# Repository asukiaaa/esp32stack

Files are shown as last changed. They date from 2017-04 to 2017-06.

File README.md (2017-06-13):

# ESP32Stack
A kicad project of stacking board with using ESP-WROOM-32.

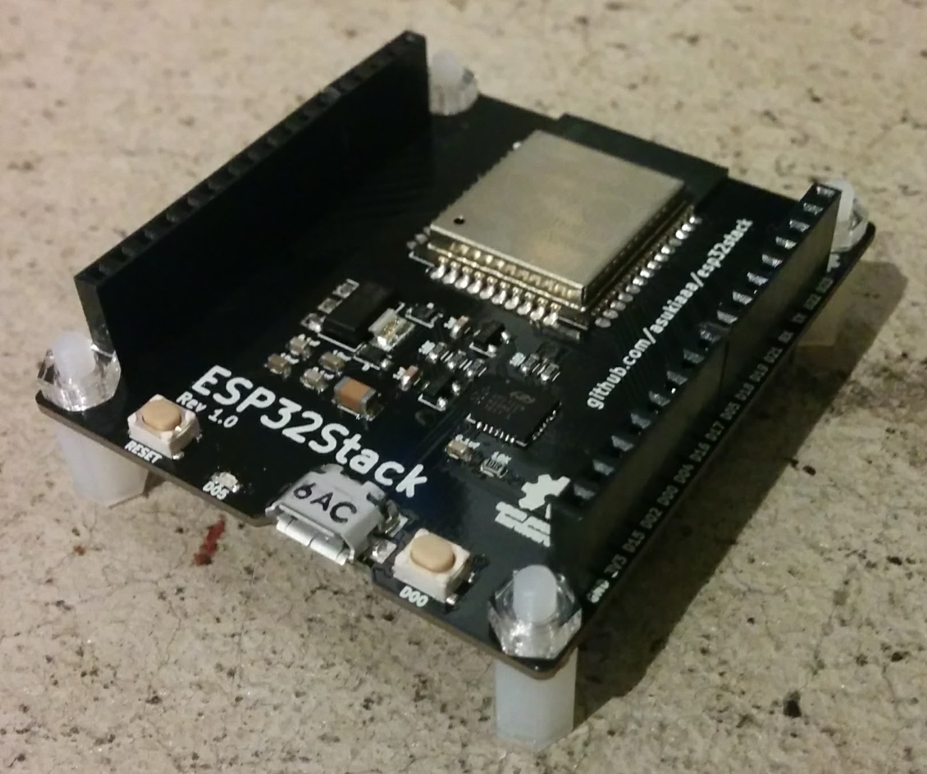
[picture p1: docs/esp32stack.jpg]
ESP32Stack

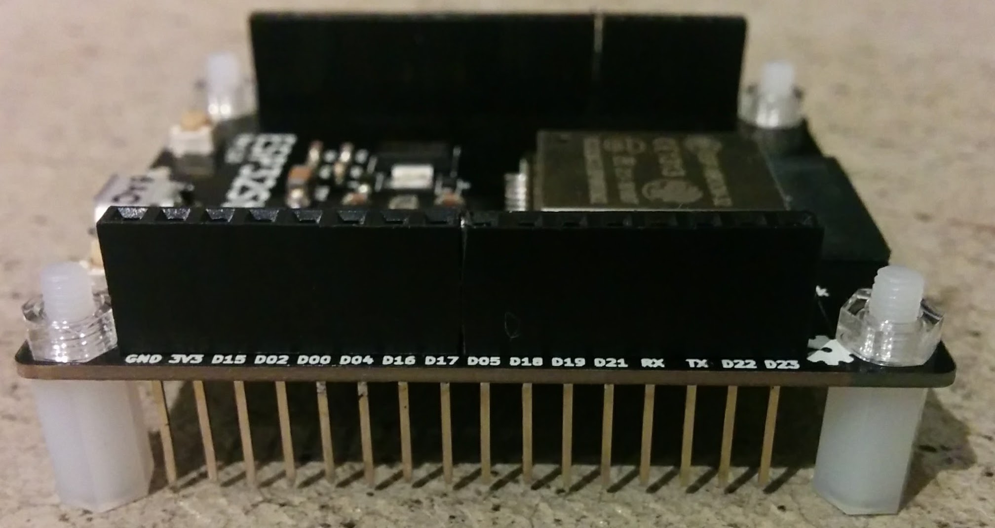
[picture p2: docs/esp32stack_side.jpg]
ESP32Stack side

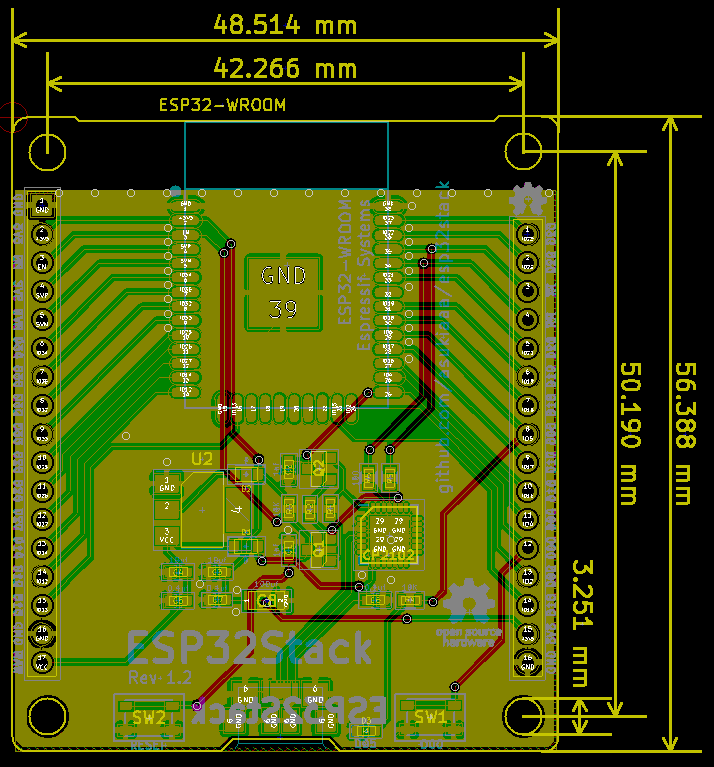
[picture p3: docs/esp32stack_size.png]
ESP32Stack size


In combination with [EmptyStack](https://github.com/asukiaaa/emptystack).
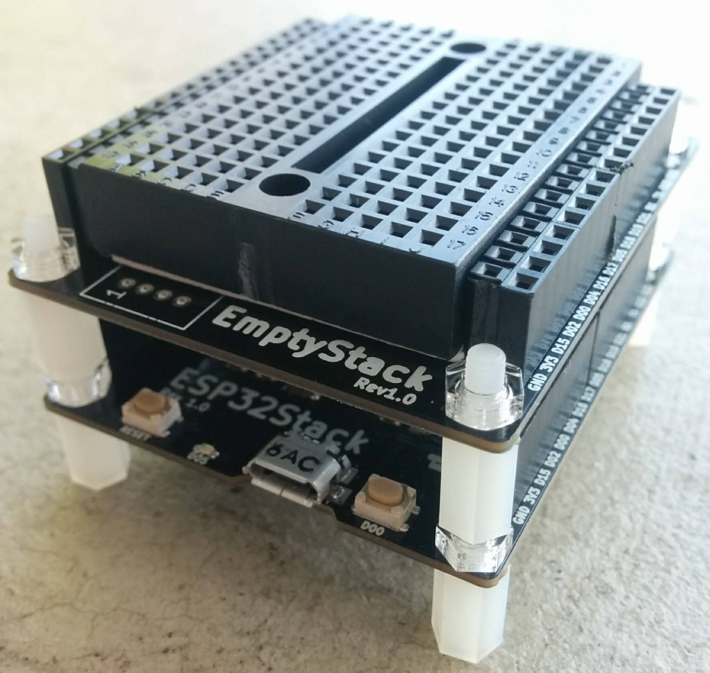
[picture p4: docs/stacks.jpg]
Stacks


[schema](docs/esp32stack.pdf)

# Driver
This board uses CP2102 for serial communication.
For mac and windiws user, please install the following driver.
Linux supports cp2102 defaul, so linux user does not need any driver.

[CP210x USB to UART Bridge VCP Drivers](http://www.silabs.com/products/development-tools/software/usb-to-uart-bridge-vcp-drivers)

# Shop
[trial stacks](https://trialstacks.base.ec/items/6243777)

# Components
- [esp-wroop-32](http://akizukidenshi.com/catalog/g/gM-11647/)
- [Hirose-microB-USB](http://akizukidenshi.com/catalog/g/gC-05254/)
- [Diode](http://akizukidenshi.com/catalog/g/gI-05951/)
- [transistor MMBT3904](http://akizukidenshi.com/catalog/g/gI-05969/)
- [switch SKRPACE010](http://akizukidenshi.com/catalog/g/gP-06185/)
- [100uf 1206 condensor](http://akizukidenshi.com/catalog/g/gP-08260/)
- [10uf 0603 condensor](http://akizukidenshi.com/catalog/g/gP-07768/)
- [0.1uf 0603 condensor](http://akizukidenshi.com/catalog/g/gP-04940/)
- [1nf (1000pf) 0603 condensor](http://akizukidenshi.com/catalog/g/gP-09285/)
- [10k 0603 registor](http://akizukidenshi.com/catalog/g/gR-06103/)
- [led](http://akizukidenshi.com/catalog/g/gI-06417/)
- [CP2102](https://www.aliexpress.com/item/5pcs-Free-shipping-SILABS-CP2102-GMR-CP2102-QFN-28-offen-use-laptop-chip-100-new-original/32503317767.html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)
- [NCP1117ST33T3G](https://www.aliexpress.com/item/Free-Shipping-NCP1117ST33T3G-NCP1117-3-3V-linear-regulator-SOT-223-package/32244660148.html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)

# Footprints
- [ESP32-kiCAD-Footprints](https://github.com/adamjvr/ESP32-kiCAD-Footprints)
- [switch: SKRPACE010.kicad_mod](https://github.com/nosuz/kicad-lib/blob/master/module.pretty/SKRPACE010.kicad_mod)

# Programing software tools
ESP32Stack is a ESP-WROOM-32 breakout board so you can write your own program by usinig the following tools.

- [espressif/esp-idf](https://github.com/espressif/esp-idf)
- [espressif/arduino-esp32](https://github.com/espressif/arduino-esp32)
- [Mongoose OS](https://mongoose-os.com/)
- etc

# License
MIT

# References
- [ESP32-Core-Board-V2_sch.pdf](http://akizukidenshi.com/download/ds/espressifsystems/ESP32-Core-Board-V2_sch.pdf)
- [esp_wroom_32_datasheet_en.pdf](https://espressif.com/sites/default/files/documentation/esp_wroom_32_datasheet_en.pdf)
- [Enginursday: First Impressions of the ESP32](https://www.sparkfun.com/news/2017)
- [ESP32 Development Board with TELEC Memorial photograph](https://macsbug.wordpress.com/2016/12/12/esp32-development-board-with-telec-memorial-photograph/)
- [DS_FT232R](http://www.ftdichip.com/Support/Documents/DataSheets/ICs/DS_FT232R.pdf)
- [SparkFun FTDI Basic Breakout - 3.3V](https://www.sparkfun.com/products/9873)
- [Sehematic of SparkFun FTDI Basic Breakout - 3.3V](http://cdn.sparkfun.com/datasheets/BreakoutBoards/FTDI%20Basic-v22-3.3V.pdf)
- [esp32-thing.sch](https://cdn.sparkfun.com/assets/learn_tutorials/5/0/7/esp32-thing-schematic.pdf)
- [The Internet of Things with ESP32](http://esp32.net/)
- [ESP-WROVER-KIT_SCH-2.pdf](https://dl.espressif.com/dl/schematics/ESP-WROVER-KIT_SCH-2.pdf)
- [ESP32-EVB_Rev_A.pdf](https://github.com/OLIMEX/ESP32-EVB/blob/master/HARDWARE/REV-A/ESP32-EVB_Rev_A.pdf)

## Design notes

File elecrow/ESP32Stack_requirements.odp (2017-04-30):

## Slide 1

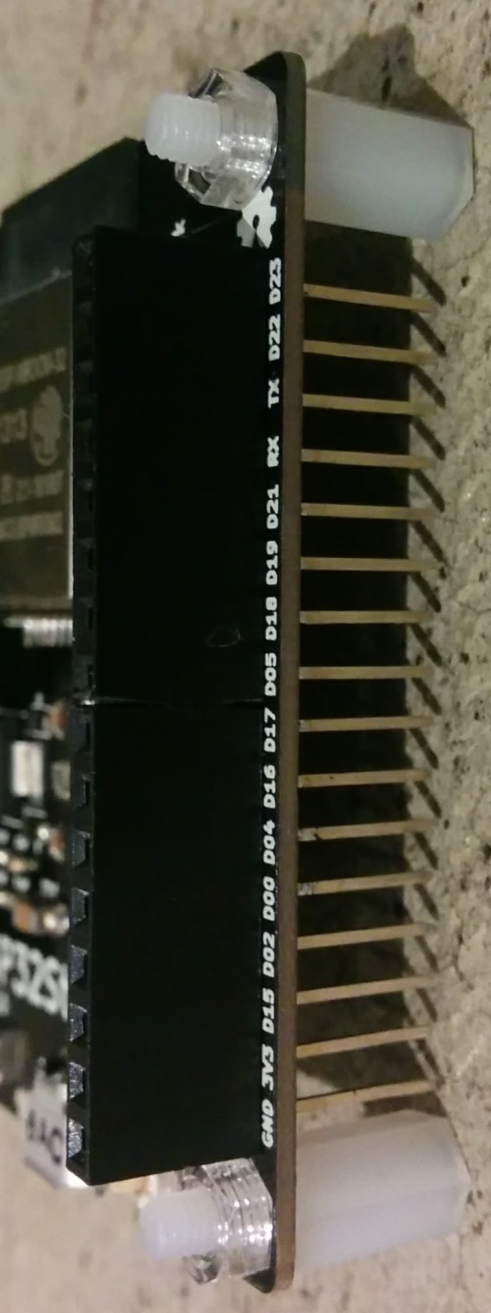
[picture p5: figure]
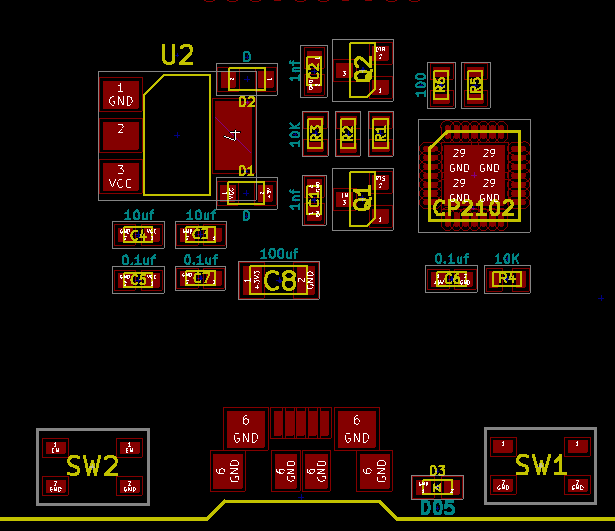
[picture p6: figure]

Component labels

Front

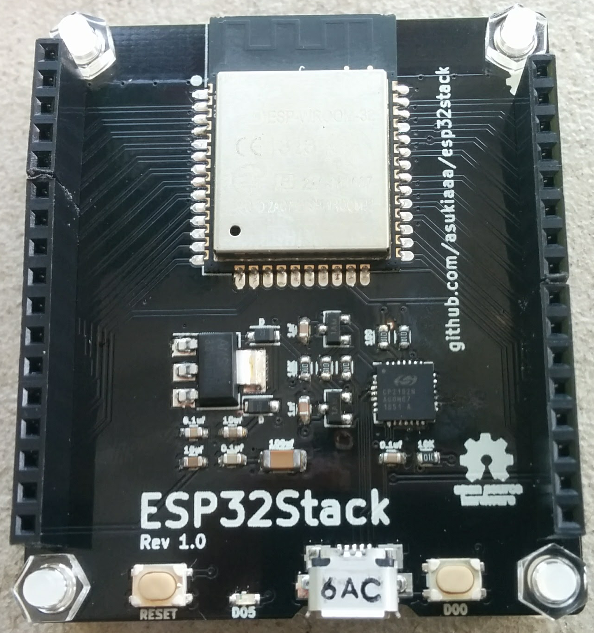
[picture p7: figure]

ESP32 module that has

TELEC mark

Side

Long leg

pin socket

(female)

Diode

→

←

Diode

Diode

←

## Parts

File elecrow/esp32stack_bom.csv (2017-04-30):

Elecrow pn | Reference | Value | Footprint | url | memo
 | P1 | USB_OTG | usb_micro_b:USB_MICRO_B-HIROSE-ZX62R-B-5P | http://www.mouser.jp/ProductDetail/Hirose-Connector/ZX62R-B-5P/?qs=XQjbzJWzFPUqfCc9Mb2Taw==
1023510A(10K) | R1,R2,R3,R4 | 10K | Resistors_SMD:R_0603
10240102A(100) | R5,R6 | 100 | Resistors_SMD:R_0603
2011501A(1nf) | C1,C2 | 1nf | Capacitors_SMD:C_0603
2015010A(10uf) | C3,C4 | 10uf | Capacitors_SMD:C_0603
 | C5,C6,C7 | 0.1uf | Capacitors_SMD:C_0603 | http://www.mouser.jp/ProductDetail/Yageo/CC0603JRNPO9BN101/?qs=AgBp2OyFlx%252bc5vUOLFsmXA== | There is no 0.1uf capacitor on list of Elecrow Parts Library. If you have any stock of 0603 size 0.1nf capacitor, please use that.
 | C8 | 100uf | Capacitors_SMD:C_1206 | http://www.mouser.jp/ProductDetail/Taiyo-Yuden/JMK316ABJ107ML-T/?qs=CNQs48zzdnrnxCTArzOO1A==
 | D1,D2 | D | common:D_0805 | http://www.mouser.jp/ProductDetail/ROHM-Semiconductor/RSX101VA-30TR/?qs=4kLU8WoGk0tB41wg4aRbGQ==
4040706A(green) | D3 | D05 | LEDs:LED_0603
 | J1 | CONN_01X17 | common:Pin_Header_Straight_1x17_Pitch2.54mm | https://www.aliexpress.com/item/8-5-0-0-10-5mm-0-1-pitch-0-4U-gold-plated-1x20-Stacking-Header/32676523255.html | Footprint is pinheader(male) but expected component is pinsocket(female) Cut the component to 17 pins or use similar one it has around 10mm length pin.
 | J2 | CONN_01X16 | common:Pin_Header_Straight_1x16_Pitch2.54mm | https://www.aliexpress.com/item/8-5-0-0-10-5mm-0-1-pitch-0-4U-gold-plated-1x20-Stacking-Header/32676523255.html | Footprint is pinheader(male) but expected component is pinsocket(female) Cut the component to 16 pins or use similar one it has around 10mm length pin.
4020290A | Q1,Q2 | MMBT3904 | TO_SOT_Packages_SMD:SOT-23
 | SW1,SW2 | SWITCH_SPST | switch:SKRPACE010 | http://www.mouser.jp/ProductDetail/ALPS/SKRPACE010/?qs=m0BA540hBPehI%2flbUxNGuw==
 | U1 | ESP32-WROOM | ESP32-footprints-Lib:ESP32-WROOM | http://akizukidenshi.com/catalog/g/gM-11850/ | Please use modules that have telec mark.
 | U2 | NCP1117ST33T3G | TO_SOT_Packages_SMD:SOT-223 | http://www.mouser.jp/ProductDetail/ON-Semiconductor/NCP1117ST33T3G/
 | U3 | CP2102 | Housings_DFN_QFN:QFN-28-1EP_5x5mm_Pitch0.5mm | http://www.mouser.jp/ProductDetail/Silicon-Labs/CP2102N-A01-GQFN28/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

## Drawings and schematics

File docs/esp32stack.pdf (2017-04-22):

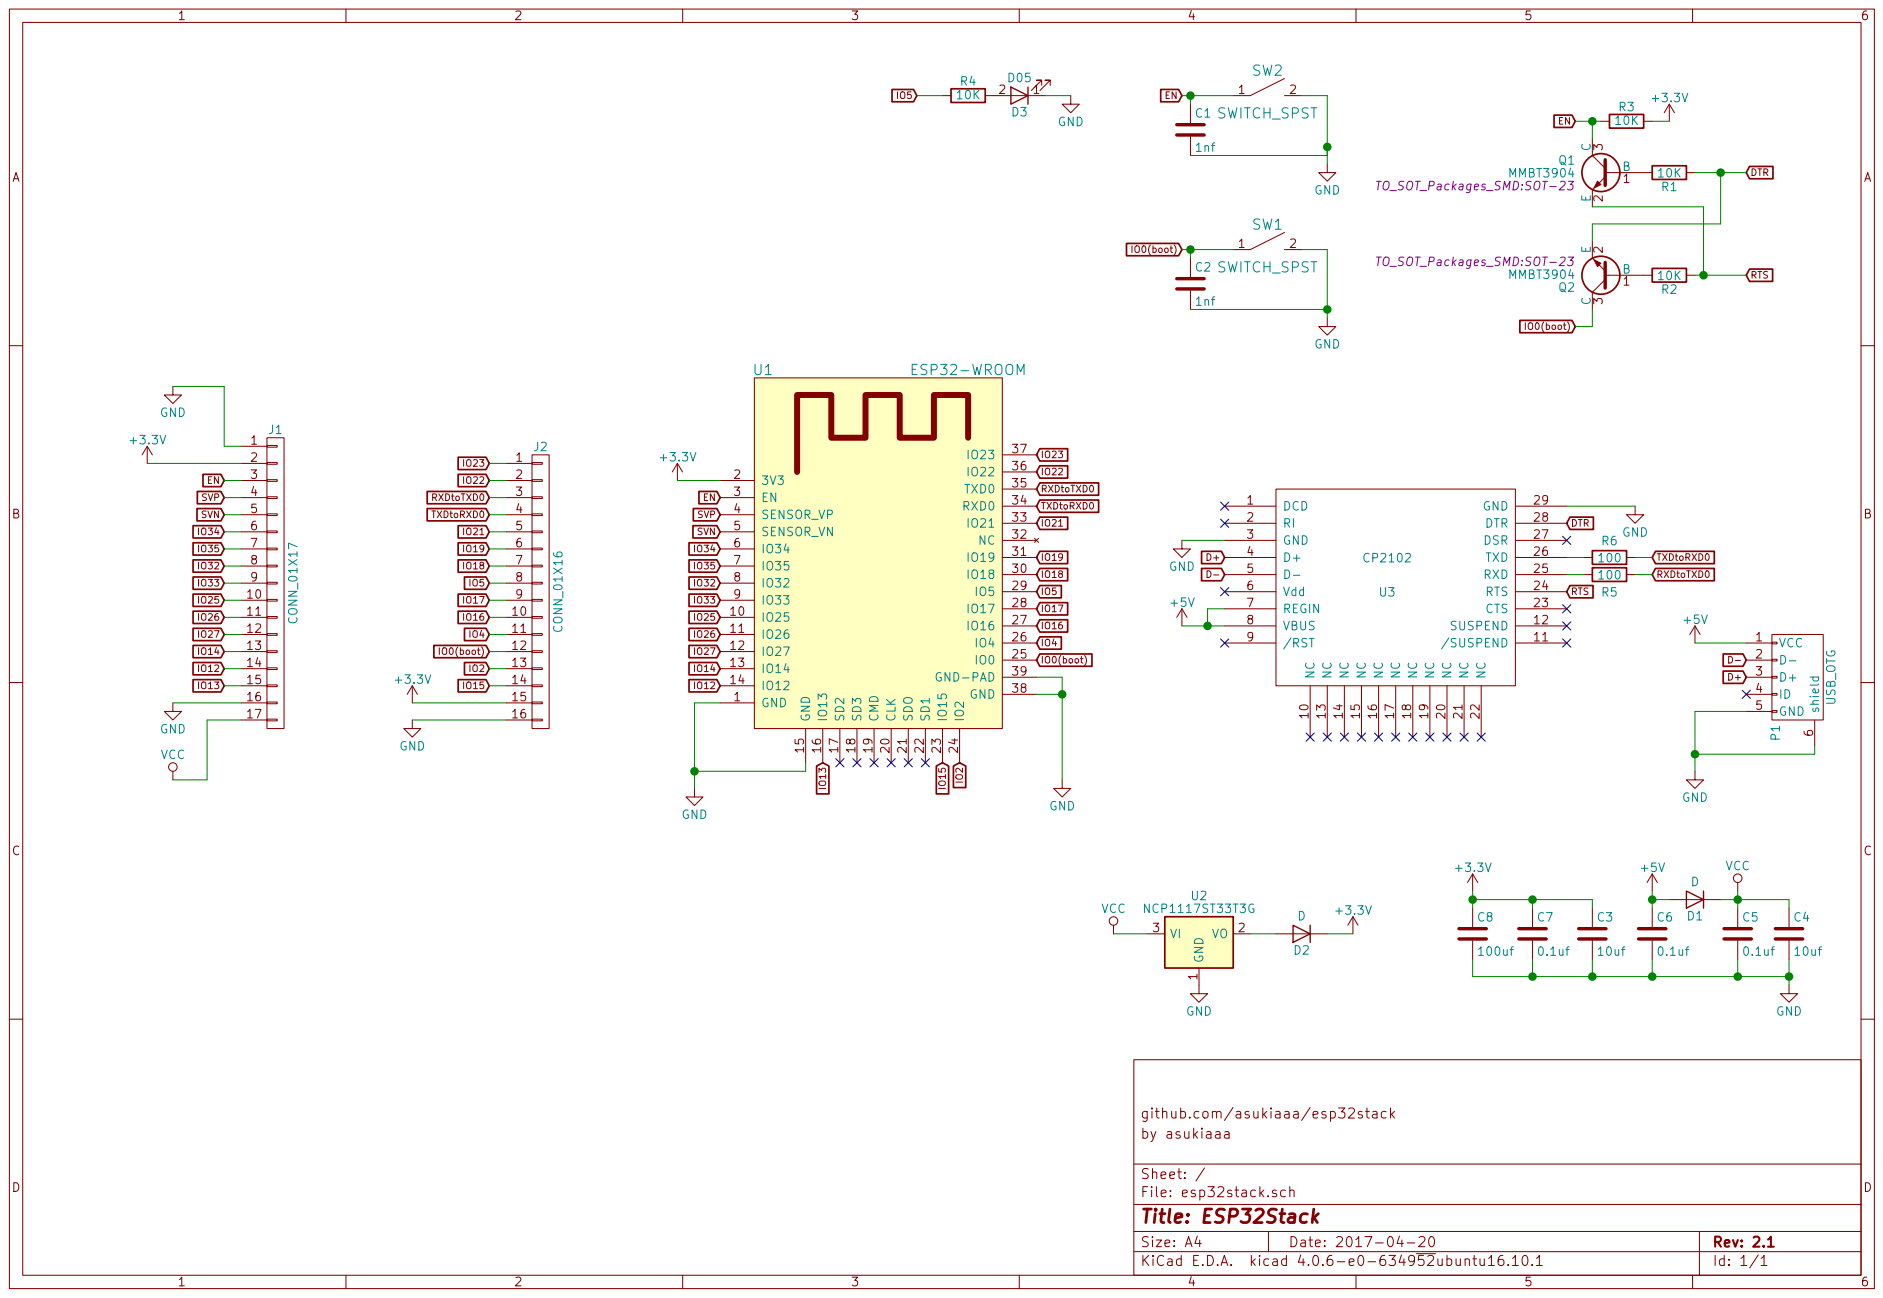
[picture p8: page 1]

github.com/asukiaaa/esp32stack
File: esp32stack.sch Sheet: / by asukiaaa

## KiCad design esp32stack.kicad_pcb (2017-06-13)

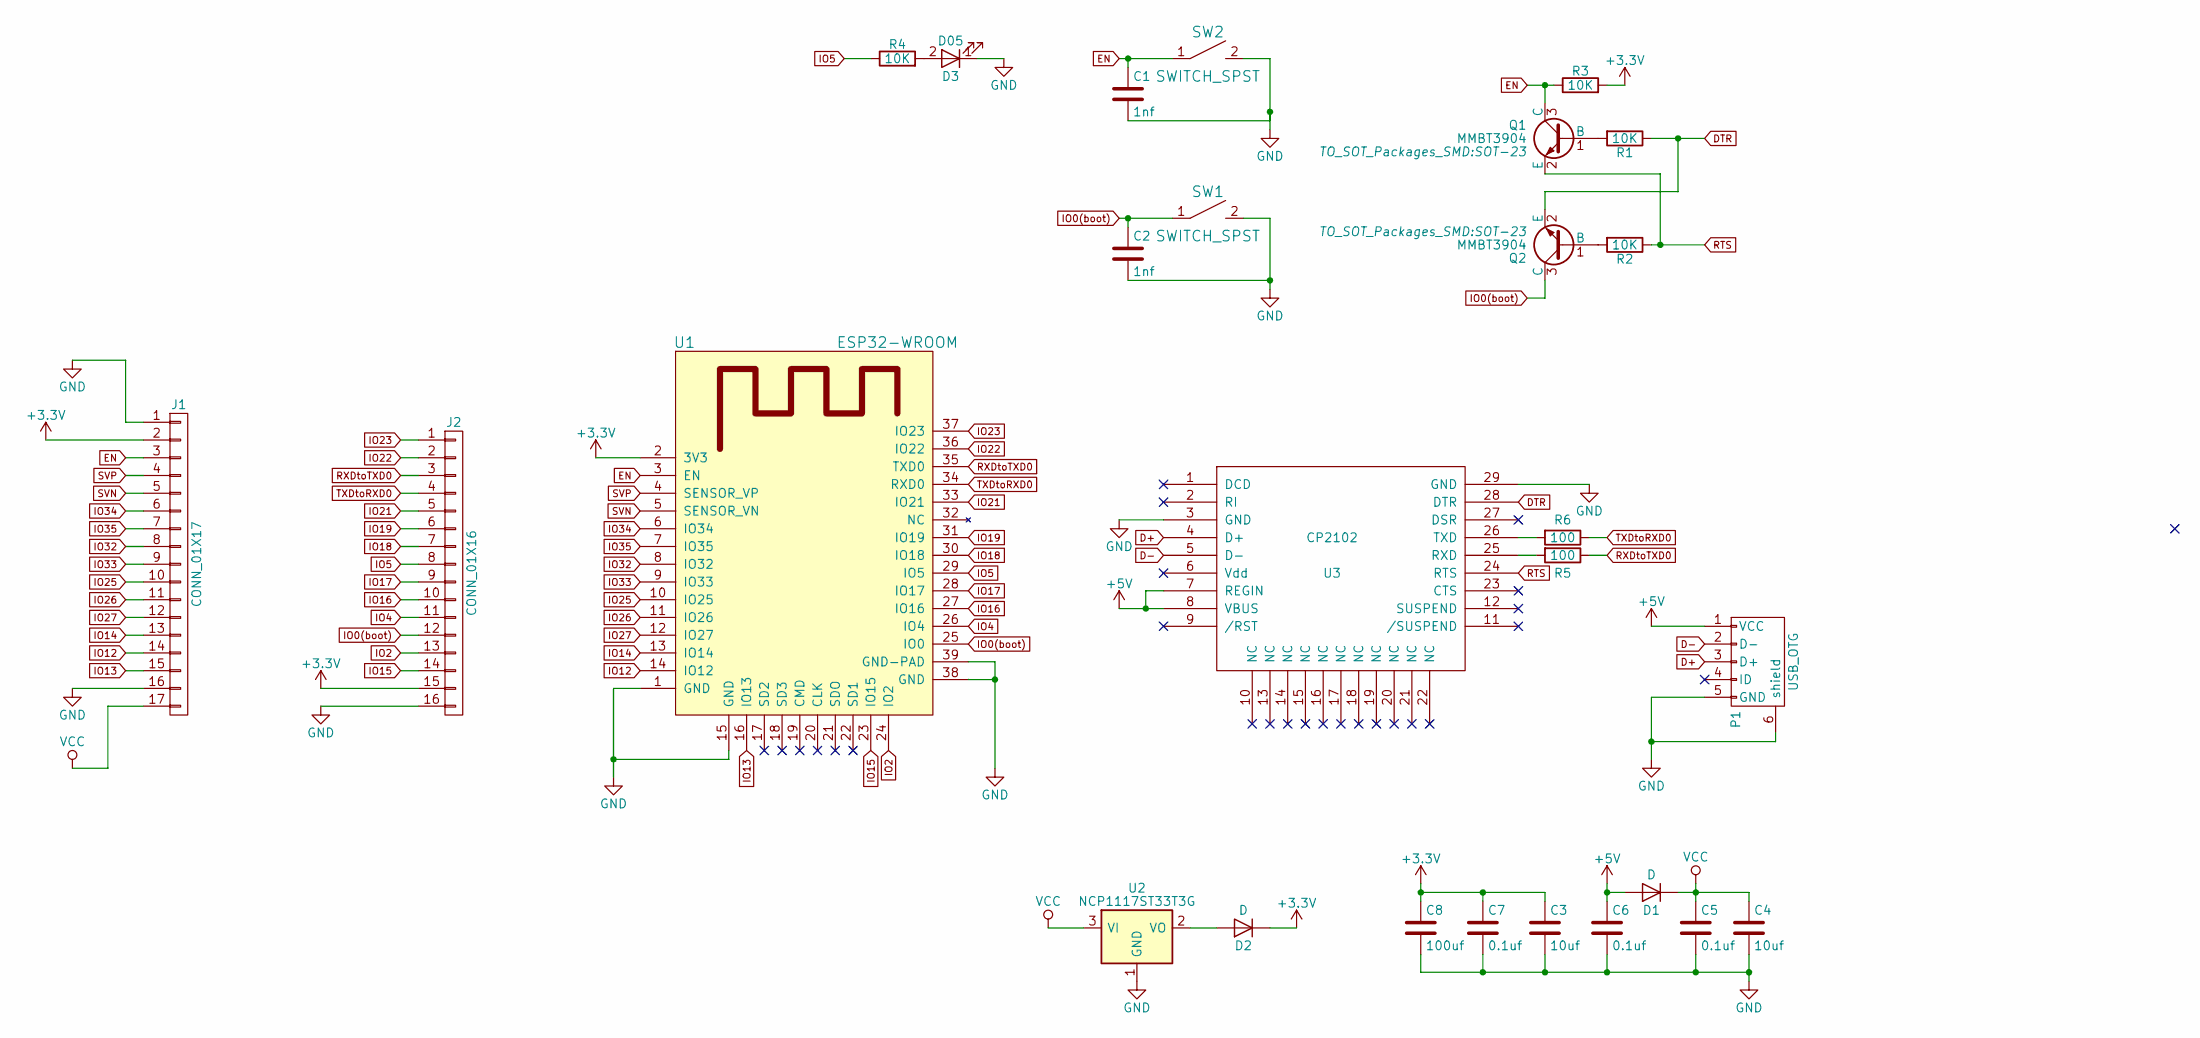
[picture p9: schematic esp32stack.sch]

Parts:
C1, C2: 1nf; C_0603
C3, C4: 10uf; C_0603
C5, C6, C7: 0.1uf; C_0603
C8: 100uf; C_1206
D1, D2: D; D_0805
D3: D05; LED_0603
J1: CONN_01X17; Pin_Header_Straight_1x17_Pitch2.54mm
J2: CONN_01X16; Pin_Header_Straight_1x16_Pitch2.54mm
P1: USB_OTG; USB_MICRO_B-HIROSE-ZX62R-B-5P
Q1, Q2: MMBT3904; SOT-23
R1, R2, R3, R4: 10K; R_0603
R5, R6: 100; R_0603
SW1, SW2: SWITCH_SPST; SKRPACE010
U1: ESP32-WROOM
U2: NCP1117ST33T3G; SOT-223
U3: CP2102; QFN-28-1EP_5x5mm_Pitch0.5mm

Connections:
+3V3: C3.1, C7.1, C8.1, D2.1 (K), J1.2, J2.15, R3.2, U1.2 (3V3)
+5V: C6.1, D1.2 (A), P1.1 (VCC), U3.7 (REGIN), U3.8 (VBUS)
D+: P1.3 (D+), U3.4 (D+)
D-: P1.2 (D-), U3.5 (D-)
DTR: Q2.2 (E), R1.1, U3.28 (DTR)
EN: C1.1, J1.3, Q1.3 (C), R3.1, SW2.1, U1.3 (EN)
GND: C1.2, C2.2, C3.2, C4.2, C5.2, C6.2, C7.2, C8.2, D3.1 (K), J1.1, J1.16, J2.16, P1.5 (GND), P1.6 (shield), SW1.2, SW2.2, U1.1 (GND), U1.15 (GND), U1.38 (GND), U1.39 (GND-PAD), U2.1 (GND), U3.3 (GND), U3.29 (GND)
IO0(boot): C2.1, J2.12, Q2.3 (C), SW1.1, U1.25 (IO0)
IO2: J2.13, U1.24 (IO2)
IO4: J2.11, U1.26 (IO4)
IO5: J2.8, R4.1, U1.29 (IO5)
IO12: J1.14, U1.14 (IO12)
IO13: J1.15, U1.16 (IO13)
IO14: J1.13, U1.13 (IO14)
IO15: J2.14, U1.23 (IO15)
IO16: J2.10, U1.27 (IO16)
IO17: J2.9, U1.28 (IO17)
IO18: J2.7, U1.30 (IO18)
IO19: J2.6, U1.31 (IO19)
IO21: J2.5, U1.33 (IO21)
IO22: J2.2, U1.36 (IO22)
IO23: J2.1, U1.37 (IO23)
IO25: J1.10, U1.10 (IO25)
IO26: J1.11, U1.11 (IO26)
IO27: J1.12, U1.12 (IO27)
IO32: J1.8, U1.8 (IO32)
IO33: J1.9, U1.9 (IO33)
IO34: J1.6, U1.6 (IO34)
IO35: J1.7, U1.7 (IO35)
unnamed: D2.2 (A), U2.2 (VO)
unnamed: D3.2 (A), R4.2
unnamed: Q1.1 (B), R1.2
unnamed: Q2.1 (B), R2.2
unnamed: R5.2, U3.25 (RXD)
unnamed: R6.2, U3.26 (TXD)
RTS: Q1.2 (E), R2.1, U3.24 (RTS)
RXDtoTXD0: J2.3, R5.1, U1.35 (TXD0)
SVN: J1.5, U1.5 (SENSOR_VN)
SVP: J1.4, U1.4 (SENSOR_VP)
TXDtoRXD0: J2.4, R6.1, U1.34 (RXD0)
VCC: C4.1, C5.1, D1.1 (K), J1.17, U2.3 (VI)

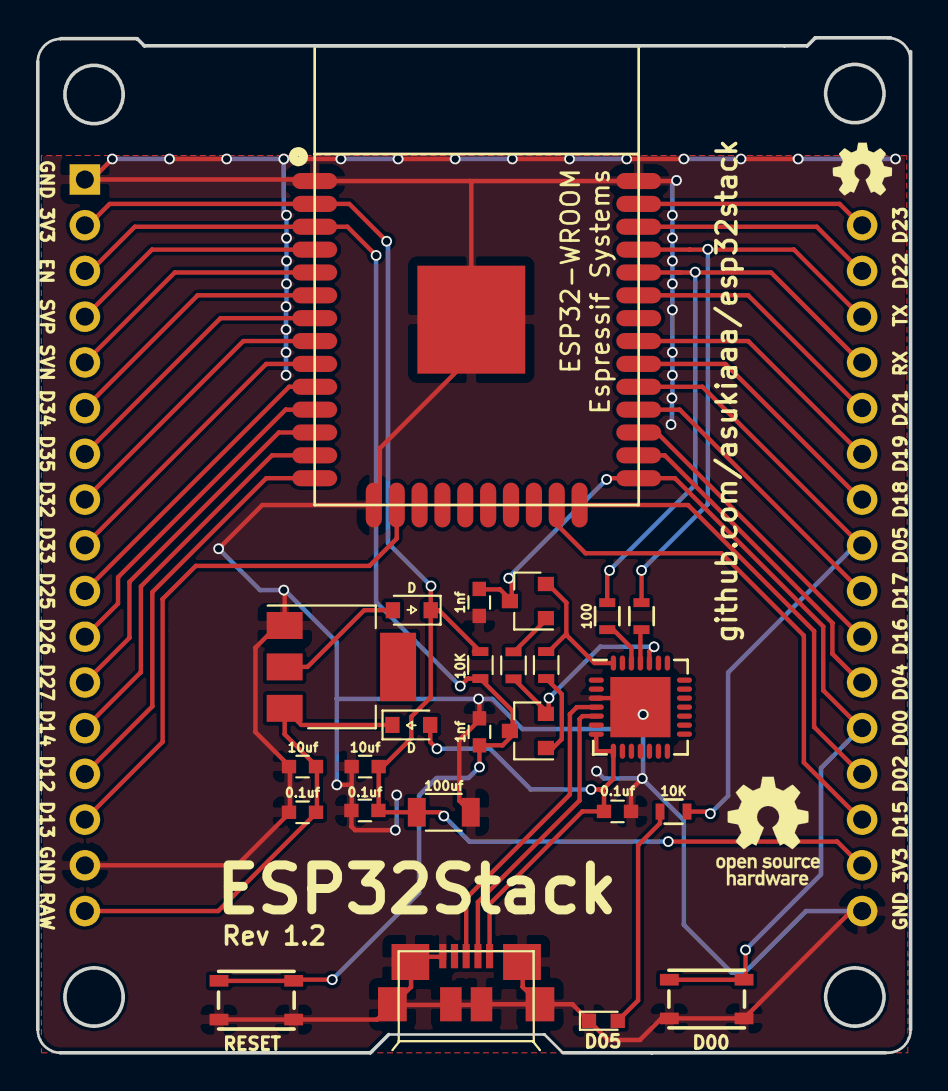
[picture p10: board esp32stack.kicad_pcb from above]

Board: 2 copper layers, 48.5 x 56.4 mm, 27 parts (0 on the bottom side), 41 nets.

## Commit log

2017-04-20 Initial commit for esp32stack rev1.0
    [esp32stack.kicad_pcb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]
2017-04-20 Add name silk to back side
    [esp32stack.kicad_pcb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]
2017-04-22 Adjust hole position
    [esp32stack.kicad_pcb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]
2017-04-26 Add length
    [esp32stack.kicad_pcb]
2017-04-28 Change condensor position
    [esp32stack.kicad_pcb]
2017-04-30 Change pcb layout for rev1.1
    [esp32stack.csv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]
2017-04-30 Rename bom file name
    [esp32stack.csv, esp32stack_bom.csv]
2017-04-30 Change usb connector and led position for rev1.2
    [esp32stack.kicad_pcb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]
2017-04-30 Add requirements for elecrow pcba order
2017-05-28 Add driver info
2017-06-13 Show hole size and position
    [esp32stack.kicad_pcb]
